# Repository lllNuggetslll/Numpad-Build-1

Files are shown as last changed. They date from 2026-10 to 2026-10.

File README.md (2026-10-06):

# Low-profile wireless numpad

A 21-key low-profile numpad: 4 columns × 6 rows, with three 2u keys ("0", "+", "Enter").

- **Controller:** nice!nano v2, running ZMK over Bluetooth.
- **Switches:** Gateron KS-33 low-profile switches in hotswap sockets.
- **Battery:** a 301230 LiPo with a low-battery LED.
- **Case:** a tilted 3D-printed case with a separate switch plate.

It's based on ceoloide's "not about money" ergogen design. The PCB is generated with
[ergogen](https://ergogen.xyz), routed with freerouting, and checked in KiCad 8. The case is generated
from the board itself, so the two always match.

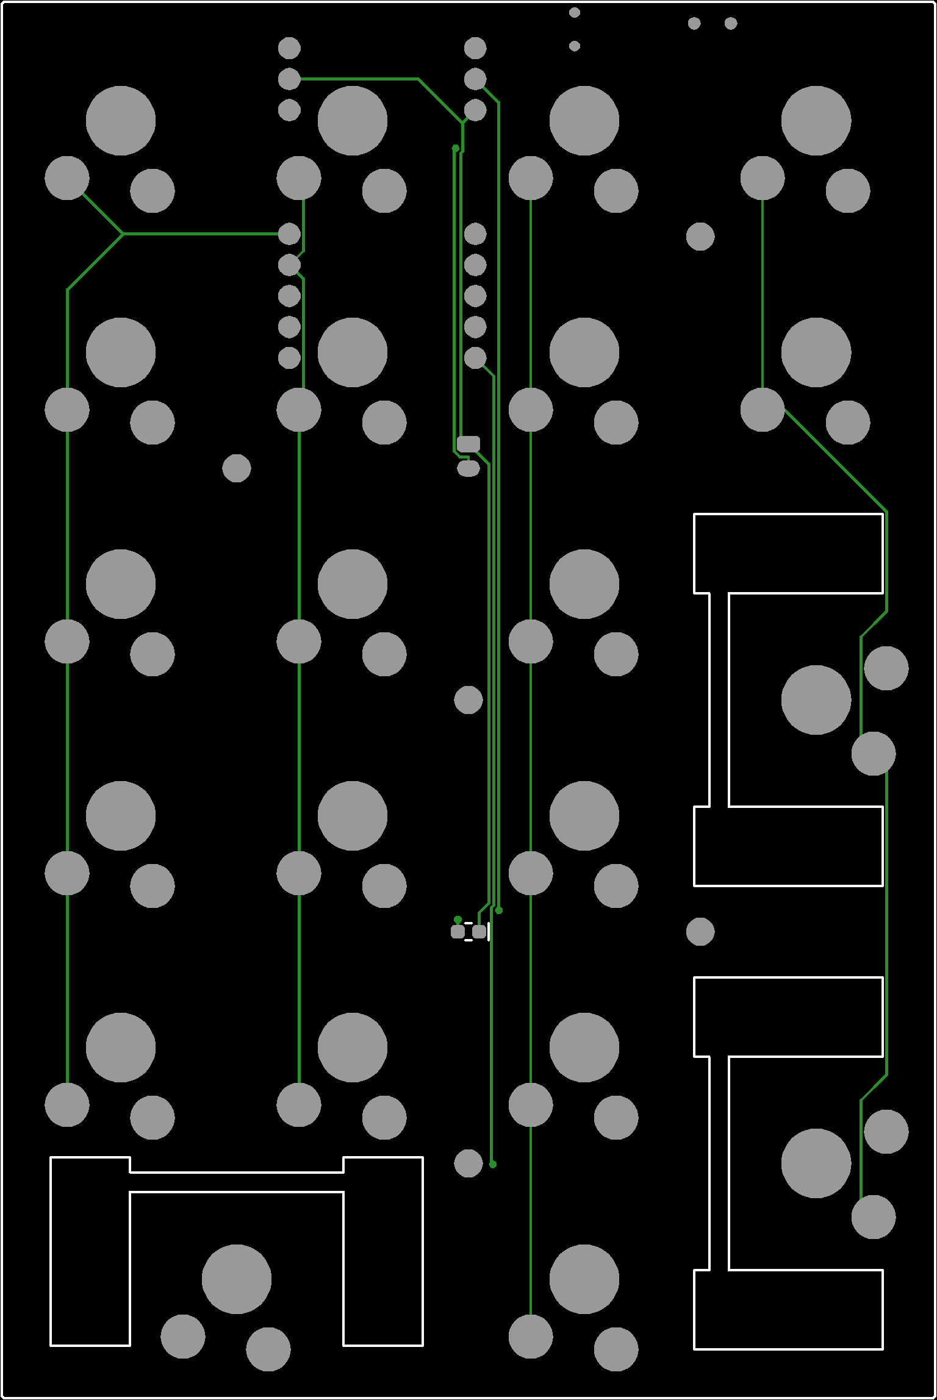
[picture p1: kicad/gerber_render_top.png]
PCB top


## Status

| Piece | State |
|---|---|
| PCB | Routed and DRC-clean. Gerbers are ready in `kicad/fab/numpad-gerbers.zip` (a PCBWay-ready package is `kicad/numpad.kicad_pcb.zip`). |
| Case and plate | `case/case_bottom.stl`, `case/case_plate.stl` |
| Firmware | Not written yet. ZMK needs a board definition using the pin map below. |

Before printing the whole plate, **test-print one stabilizer cutout**. Its notch depth and neck size come from a
drawing that isn't to scale.

## Shopping list

See **[SHOPPING_LIST.md](SHOPPING_LIST.md)**.

## Repository layout

| Path | What it is |
|---|---|
| `config.yaml` | Ergogen source of truth for the PCB: layout, footprints, outline. |
| `footprints/ceoloide/` | Upstream ceoloide footprints. |
| `footprints/custom/` | Local footprints. `mcu_nice_nano_sparse.js` adds an `omit_pins` option; `smd_0603.js` is for the LED and resistor. |
| `output/` | **Current board.** `pcbs/not_about_money.kicad_pcb` is routed (DRC report `pcbs/drc.rpt`, preview `routed.svg`); `not_about_money.unrouted.kicad_pcb` is the raw ergogen output. |
| `kicad/` | KiCad project for the current board (with the project's 0.2 mm edge-clearance rule), `fab/` (gerbers + drill + zip), and the PCBWay package `numpad.kicad_pcb.zip`. |
| `case/build_case.py` | Generates the case from the board: `case_bottom.jscad`, `case_plate.jscad`, `assembly.json`. |
| `case/viewer.html` | 3D viewer of the case, plate, PCB, parts, keycaps and battery. |
| `case/battery_fit.py` | Finds where LiPo cells fit under the tilted PCB. |
| Git history | Earlier design iterations (commit `c19e498` has every old `output_*` folder and config backup). |
| `CLAUDE.md` | Detailed design notes: coordinates, measurements, decisions, gotchas. |

## 1. Order the PCB

Upload `kicad/fab/numpad-gerbers.zip` to any PCB fab. For PCBWay, `kicad/numpad.kicad_pcb.zip` already includes their BOM, netlist and positions files. Order a 2-layer, 1.6 mm, standard-spec board. The
design values (0.25 mm tracks, 0.2 mm clearance, 0.6/0.3 mm vias) are within every fab's limits. The three
stabilizer cutouts are part of the board outline.

## 2. Print the case

- **`case/case_bottom.stl`:** print as-is (floor down). It has a 0.5 mm battery pocket in the floor and three
  windows in the back wall: USB-C, reset, and the power-switch lever. The USB-C port sits at the back of a
  12.5 × 6.5 mm recess so a cable head can reach it; the recess's back wall is flush with the port.
- **`case/case_plate.stl`:** print **upside down** (plate top on the bed). The edge rim and the spacer posts
  around the screws are on its underside.
- **Settings:** PLA or PETG, 0.2 mm layers. No supports needed.

## 3. Assemble

The switches go on the front of the PCB. **Everything else** goes on the back (side B), except the
low-battery LED, which is on the front.

1. **Trim three sockets.** On the hotswap sockets for the three 2u keys ("0", "+", "Enter"), sand
   **1.1 mm off the tip of the solder tab that points at the stabilizer cutout**, leaving about 1.4–1.5 mm of
   tab. Without this, that tab hits the stabilizer housing. Dry-fit each socket to find the right tab, then
   clean and tin it.
2. **Back side SMD parts:** solder the 21 diodes (mind the cathode band), the 21 hotswap sockets, the reset
   button, the power switch, and the 1 kΩ resistor.
3. **Front side:** solder the 0603 LED. It sits under a hole in the plate between the keycaps.
4. **Battery connector:** solder the JST PH on the back, then **trim its pins flush** on the front. They're
   3.4 mm long and the plate only leaves 1.6 mm above the PCB.
5. **nice!nano:** the controller mounts on the back, components facing **away** from the PCB, on standard
   male header pins with 2.5 mm plastic spacers.
   - Fit pins **only** where the PCB has holes: 16 pins (RAW, RST, GND ×2, P0, P1, P4–P8, P14–P16, P18,
     P19). The other 8 positions sit over switch pads and are left off on purpose.
   - Trim the pins on the front to about 1.4 mm.
6. **Battery:**
   - **Check polarity first.** On the JST footprint, the oval pad (pad 2) is **battery +** and the
     squarer pad (pad 1) is **battery −**. Many cheap LiPos have their plug wired the other way round.
     Measure with a multimeter before plugging in.
   - Stick the 301230 into the floor pocket with thin double-sided tape. Its lead runs from the notch at the
     pocket's end to the JST.
7. **Plate, stabilizers and switches:**
   - Clip the stabilizers into the plate. The wire bar faces the middle of the board.
   - Press the switches into the plate.
   - Lower the plate onto the PCB so the switch pins enter the sockets.
8. **Into the case:** angle the PCB in at the back first and slide it back, so the power lever slips
   through its window (it pokes about 0.5 mm out of the back) and the USB-C port slides into its window
   (it sits inside the wall, so it can't drop in from above). Then drop
   the front onto the pillars.
9. **Screws:** fit the countersunk M2 screws through the plate. Use **M2×8** at the back-left, back-right and
   centre pillars, and **M2×6** at the two front pillars. Tighten gently; they cut their own thread in the
   plastic.
10. **Keycaps.**

## 4. Firmware (ZMK)

The matrix is 4 columns × 6 rows, with diodes oriented column → row. The pin map below differs from the
original design, so the ZMK board/shield definition must match:

| Signal | nice!nano pin |
|---|---|
| Columns C1–C4 | P19, P18, P15, P14 |
| Row R1 | P16 |
| Rows R2–R6 | P4, P5, P6, P7, P8 |
| Low-battery LED (active high) | P0 (nRF P0.08) |
| Free spare | P1 |

VCC (3.3 V out) isn't connected. ZMK has no built-in low-battery LED, so blinking P0 when the battery is low
needs a small custom module. Keep it to a blink, because a steady LED drains the battery.

## Rebuilding from source

Requires ergogen v4.1.0 (`npm i -g ergogen@4.1.0`), KiCad 8 (its bundled Python provides `pcbnew`), and Java
15+ for freerouting 1.4.5.1.

1. **Generate the PCB.** Custom footprints only load when ergogen gets a *directory*. Copy `config.yaml` and
   `footprints/` into a scratch folder, then run:
   ```bash
   ergogen <scratch-folder> -o <scratch-folder>/out --clean
   ```
   Then copy `out/pcbs`, `out/outlines` and `out/cases` over the ones in `output/`. Don't point ergogen
   at `output/` directly: `--clean` empties the whole folder, including the routed board.
2. **Route it.** Export a Specctra DSN with `pcbnew.ExportSpecctraDSN`, then route:
   ```bash
   java -jar freerouting-1.4.5.1.jar -de board.dsn -do board.ses -mp 30
   ```
   Import the result with `pcbnew.ImportSpecctraSES`. Set copper-to-edge clearance to 0.2 mm (the side
   switches sit at the board edge), then run DRC:
   ```bash
   kicad-cli pcb drc --severity-error board.kicad_pcb
   ```
3. **Gerbers:**
   ```bash
   kicad-cli pcb export gerbers --output fab/ board.kicad_pcb
   ```
   ```bash
   kicad-cli pcb export drill --output fab/ board.kicad_pcb
   ```
   Then zip the `fab/` folder.
4. **Case.** Point `BOARD` at the top of `case/build_case.py` to the board, then run it with KiCad's Python. It
   prints the stack-up, a collision report, the battery spot and the screw lengths.
   ```bash
   "C:/Program Files/KiCad/8.0/bin/python.exe" case/build_case.py
   ```
   Render the jscad files to STL with the **v1** JSCAD CLI (v2 can't run them):
   ```bash
   npm install --prefix .jscad @jscad/cli@1
   ```
   ```bash
   .jscad/node_modules/.bin/openjscad case/case_bottom.jscad -o case/case_bottom.stl
   ```
   ```bash
   .jscad/node_modules/.bin/openjscad case/case_plate.jscad -o case/case_plate.stl
   ```
5. **View it.** Serve the case folder and open `http://localhost:8765/viewer.html`:
   ```bash
   python -m http.server 8765 --directory case
   ```

`CLAUDE.md` has the full design notes: the tilt and stack-up, where each part dimension came from (datasheet
vs estimate), the stabilizer geometry, and the controller pin constraints.

## Credits and licenses

- The base design and most footprints are by [ceoloide](https://github.com/ceoloide), with contributions by
  @infused-kim and @nxtk; see `footprints/ceoloide/LICENSE`.
- Some footprints are **CC BY-NC-SA 4.0**: the nice!nano and power-switch footprints, and therefore
  `footprints/custom/mcu_nice_nano_sparse.js`, which is derived from one of them. Others are MIT. Check the
  header of each file.
- The non-commercial clause means boards built from this repo shouldn't be sold.

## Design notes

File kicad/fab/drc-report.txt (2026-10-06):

** Drc report for numpad.kicad_pcb **
** Created on 2026-10-04T18:26:51-0700 **

** Found 83 DRC violations **
[silk_edge_clearance]: Silkscreen clipped by board edge
    Rule: board setup constraints silk; warning
    @(147.0000 mm, 61.2500 mm): Segment on Edge.Cuts
    @(147.5000 mm, 67.0000 mm): PCB Text 'JLCJLCJLCJLC' on B.Silkscreen
[lib_footprint_issues]: Footprint 'mounting_hole_npth' not found in library 'ceoloide'.
    Local override; warning
    @(128.5000 mm, 52.5000 mm): Footprint MH5
[lib_footprint_issues]: Footprint 'mounting_hole_npth' not found in library 'ceoloide'.
    Local override; warning
    @(147.5000 mm, 71.5000 mm): Footprint MH3
[lib_footprint_issues]: Footprint 'mounting_hole_npth' not found in library 'ceoloide'.
    Local override; warning
    @(128.5000 mm, 90.5000 mm): Footprint MH4
[lib_footprint_issues]: Footprint 'mounting_hole_npth' not found in library 'ceoloide'.
    Local override; warning
    @(147.5000 mm, 14.5000 mm): Footprint MH2
[lib_footprint_issues]: The current configuration does not include the library 'custom'.
    Local override; warning
    @(128.5000 mm, 71.5000 mm): Footprint LED1
[lib_footprint_issues]: Footprint 'mounting_hole_npth' not found in library 'ceoloide'.
    Local override; warning
    @(109.5000 mm, 33.5000 mm): Footprint MH1
[lib_footprint_issues]: Footprint 'switch_gateron_ks27_ks33' not found in library 'ceoloide'.
    Local override; warning
    @(157.0000 mm, 90.5000 mm): Footprint S20
[lib_footprint_issues]: Footprint 'switch_gateron_ks27_ks33' not found in library 'ceoloide'.
    Local override; warning
    @(119.0000 mm, 5.0000 mm): Footprint S10
[lib_footprint_issues]: Footprint 'mcu_nice_nano' not found in library 'ceoloide'.
    Local override; warning
    @(121.4400 mm, 11.7500 mm): Footprint MCU1
[lib_footprint_issues]: Footprint 'diode_tht_sod123' not found in library 'ceoloide'.
    Local override; warning
    @(107.1000 mm, 3.7500 mm): Footprint D6
[lib_footprint_issues]: Footprint 'switch_gateron_ks27_ks33' not found in library 'ceoloide'.
    Local override; warning
    @(119.0000 mm, 24.0000 mm): Footprint S9
[lib_footprint_issues]: Footprint 'diode_tht_sod123' not found in library 'ceoloide'.
    Local override; warning
    @(126.1000 mm, 60.7500 mm): Footprint D8
[lib_footprint_issues]: Footprint 'diode_tht_sod123' not found in library 'ceoloide'.
    Local override; warning
    @(107.1000 mm, 22.7500 mm): Footprint D5
[lib_footprint_issues]: Footprint 'switch_gateron_ks27_ks33' not found in library 'ceoloide'.
    Local override; warning
    @(119.0000 mm, 62.0000 mm): Footprint S7
[lib_footprint_issues]: Footprint 'switch_gateron_ks27_ks33' not found in library 'ceoloide'.
    Local override; warning
    @(100.0000 mm, 5.0000 mm): Footprint S5
[lib_footprint_issues]: Footprint 'diode_tht_sod123' not found in library 'ceoloide'.
    Local override; warning
    @(116.6000 mm, 98.7500 mm): Footprint D1
[lib_footprint_issues]: Footprint 'switch_gateron_ks27_ks33' not found in library 'ceoloide'.
    Local override; warning
    @(157.0000 mm, 5.0000 mm): Footprint S18
[lib_footprint_issues]: Footprint 'diode_tht_sod123' not found in library 'ceoloide'.
    Local override; warning
    @(164.1000 mm, 89.2500 mm): Footprint D18
[lib_footprint_issues]: Footprint 'switch_gateron_ks27_ks33' not found in library 'ceoloide'.
    Local override; warning
    @(100.0000 mm, 62.0000 mm): Footprint S2
[lib_footprint_issues]: Footprint 'diode_tht_sod123' not found in library 'ceoloide'.
    Local override; warning
    @(145.1000 mm, 79.7500 mm): Footprint D13
[lib_footprint_issues]: Footprint 'diode_tht_sod123' not found in library 'ceoloide'.
    Local override; warning
    @(145.1000 mm, 98.7500 mm): Footprint D12
[lib_footprint_issues]: Footprint 'diode_tht_sod123' not found in library 'ceoloide'.
    Local override; warning
    @(126.1000 mm, 22.7500 mm): Footprint D10
[lib_footprint_issues]: Footprint 'diode_tht_sod123' not found in library 'ceoloide'.
    Local override; warning
    @(107.1000 mm, 41.7500 mm): Footprint D4
[lib_footprint_issues]: Footprint 'diode_tht_sod123' not found in library 'ceoloide'.
    Local override; warning
    @(126.1000 mm, 3.7500 mm): Footprint D11
[lib_footprint_issues]: Footprint 'switch_gateron_ks27_ks33' not found in library 'ceoloide'.
    Local override; warning
    @(138.0000 mm, 62.0000 mm): Footprint S13
[lib_footprint_issues]: Footprint 'switch_gateron_ks27_ks33' not found in library 'ceoloide'.
    Local override; warning
    @(138.0000 mm, 5.0000 mm): Footprint S16
[lib_footprint_issues]: Footprint 'switch_gateron_ks27_ks33' not found in library 'ceoloide'.
    Local override; warning
    @(138.0000 mm, 100.0000 mm): Footprint S11
[lib_footprint_issues]: Footprint 'diode_tht_sod123' not found in library 'ceoloide'.
    Local override; warning
    @(107.1000 mm, 79.7500 mm): Footprint D2
[lib_footprint_issues]: Footprint 'diode_tht_sod123' not found in library 'ceoloide'.
    Local override; warning
    @(126.1000 mm, 41.7500 mm): Footprint D9
[lib_footprint_issues]: Footprint 'switch_gateron_ks27_ks33' not found in library 'ceoloide'.
    Local override; warning
    @(157.0000 mm, 24.0000 mm): Footprint S17
[lib_footprint_issues]: Footprint 'switch_gateron_ks27_ks33' not found in library 'ceoloide'.
    Local override; warning
    @(119.0000 mm, 81.0000 mm): Footprint S6
[lib_footprint_issues]: Footprint 'battery_connector_jst_ph_2' not found in library 'ceoloide'.
    Local override; warning
    @(128.5000 mm, 32.5000 mm): Footprint JST1
[lib_footprint_issues]: Footprint 'switch_gateron_ks27_ks33' not found in library 'ceoloide'.
    Local override; warning
    @(109.5000 mm, 100.0000 mm): Footprint S19
[lib_footprint_issues]: The current configuration does not include the library 'custom'.
    Local override; warning
    @(128.5000 mm, 71.5000 mm): Footprint R1
[lib_footprint_issues]: Footprint 'switch_gateron_ks27_ks33' not found in library 'ceoloide'.
    Local override; warning
    @(119.0000 mm, 43.0000 mm): Footprint S8
[lib_footprint_issues]: Footprint 'switch_gateron_ks27_ks33' not found in library 'ceoloide'.
    Local override; warning
    @(100.0000 mm, 43.0000 mm): Footprint S3
[lib_footprint_issues]: Footprint 'diode_tht_sod123' not found in library 'ceoloide'.
    Local override; warning
    @(164.1000 mm, 51.2500 mm): Footprint D19
[lib_footprint_issues]: Footprint 'diode_tht_sod123' not found in library 'ceoloide'.
    Local override; warning
    @(145.1000 mm, 22.7500 mm): Footprint D16
[lib_footprint_issues]: Footprint 'switch_gateron_ks27_ks33' not found in library 'ceoloide'.
    Local override; warning
    @(100.0000 mm, 81.0000 mm): Footprint S1
[lib_footprint_issues]: Footprint 'diode_tht_sod123' not found in library 'ceoloide'.
    Local override; warning
    @(145.1000 mm, 3.7500 mm): Footprint D17
[lib_footprint_issues]: Footprint 'diode_tht_sod123' not found in library 'ceoloide'.
    Local override; warning
    @(145.1000 mm, 60.7500 mm): Footprint D14
[lib_footprint_issues]: Footprint 'diode_tht_sod123' not found in library 'ceoloide'.
    Local override; warning
    @(126.1000 mm, 79.7500 mm): Footprint D7
[lib_footprint_issues]: Footprint 'diode_tht_sod123' not found in library 'ceoloide'.
    Local override; warning
    @(145.1000 mm, 41.7500 mm): Footprint D15
[lib_footprint_issues]: Footprint 'switch_gateron_ks27_ks33' not found in library 'ceoloide'.
    Local override; warning
    @(138.0000 mm, 43.0000 mm): Footprint S14
[lib_footprint_issues]: Footprint 'switch_gateron_ks27_ks33' not found in library 'ceoloide'.
    Local override; warning
    @(157.0000 mm, 52.5000 mm): Footprint S21
[lib_footprint_issues]: Footprint 'diode_tht_sod123' not found in library 'ceoloide'.
    Local override; warning
    @(164.1000 mm, 3.7500 mm): Footprint D21
[lib_footprint_issues]: Footprint 'power_switch_smd_side' not found in library 'ceoloide'.
    Local override; warning
    @(148.5000 mm, -2.9550 mm): Footprint PWR1
[lib_footprint_issues]: Footprint 'diode_tht_sod123' not found in library 'ceoloide'.
    Local override; warning
    @(164.1000 mm, 22.7500 mm): Footprint D20
[lib_footprint_issues]: Footprint 'diode_tht_sod123' not found in library 'ceoloide'.
    Local override; warning
    @(107.1000 mm, 60.7500 mm): Footprint D3
[lib_footprint_issues]: Footprint 'switch_gateron_ks27_ks33' not found in library 'ceoloide'.
    Local override; warning
    @(100.0000 mm, 24.0000 mm): Footprint S4
[lib_footprint_issues]: Footprint 'switch_gateron_ks27_ks33' not found in library 'ceoloide'.
    Local override; warning
    @(138.0000 mm, 81.0000 mm): Footprint S12
[lib_footprint_issues]: Footprint 'reset_switch_smd_side' not found in library 'ceoloide'.
    Local override; warning
    @(137.2000 mm, -2.5000 mm): Footprint RST1
[lib_footprint_issues]: Footprint 'switch_gateron_ks27_ks33' not found in library 'ceoloide'.
    Local override; warning
    @(138.0000 mm, 24.0000 mm): Footprint S15
[silk_over_copper]: Silkscreen clipped by solder mask
    Local override; warning
    @(147.5000 mm, 29.5000 mm): PCB Text ''Not about money' v0.1 by ceoloide' on B.Silkscreen
[silk_over_copper]: Silkscreen clipped by solder mask
    Local override; warning
    @(147.5000 mm, 67.0000 mm): PCB Text 'JLCJLCJLCJLC' on B.Silkscreen
[silk_over_copper]: Silkscreen clipped by solder mask
    Local override; warning
    @(115.1500 mm, -2.2800 mm): Segment on B.Silkscreen
[silk_over_copper]: Silkscreen clipped by solder mask
    Local override; warning
    @(115.1500 mm, 28.3200 mm): Segment on B.Silkscreen
[silk_over_copper]: Silkscreen clipped by solder mask
    Local override; warning
    @(130.3900 mm, -2.2800 mm): Segment on B.Silkscreen
[silk_over_copper]: Silkscreen clipped by solder mask
    Local override; warning
    @(130.3900 mm, 28.3200 mm): Segment on B.Silkscreen
[silk_over_copper]: Silkscreen clipped by solder mask
    Local override; warning
    @(125.9100 mm, 21.9100 mm): Footprint Text 'R5' of MCU1
[silk_over_copper]: Silkscreen clipped by solder mask
    Local override; warning
    @(116.9700 mm, 6.6700 mm): Footprint Text 'V+' of MCU1
[silk_over_copper]: Silkscreen clipped by solder mask
    Local override; warning
    @(116.9700 mm, 21.9100 mm): Footprint Text 'C4' of MCU1
[silk_over_copper]: Silkscreen clipped by solder mask
    Local override; warning
    @(125.9100 mm, 24.4500 mm): Footprint Text 'R6' of MCU1
[silk_over_copper]: Silkscreen clipped by solder mask
    Local override; warning
    @(116.9700 mm, 24.4500 mm): Footprint Text 'R1' of MCU1
[silk_over_copper]: Silkscreen clipped by solder mask
    Local override; warning
    @(116.9700 mm, 4.1300 mm): Footprint Text 'RS' of MCU1
[silk_over_copper]: Silkscreen clipped by solder mask
    Local override; warning
    @(163.7000 mm, 89.0000 mm): Segment on B.Silkscreen
[silk_over_copper]: Silkscreen clipped by solder mask
    Local override; warning
    @(164.1000 mm, 89.0000 mm): Segment on B.Silkscreen
[silk_over_copper]: Silkscreen clipped by solder mask
    Local override; warning
    @(164.1000 mm, 89.6000 mm): Segment on B.Silkscreen
[silk_over_copper]: Silkscreen clipped by solder mask
    Local override; warning
    @(134.8600 mm, 29.4400 mm): Segment on B.Silkscreen
[silk_over_copper]: Silkscreen clipped by solder mask
    Local override; warning
    @(134.8600 mm, 30.3600 mm): Segment on B.Silkscreen
[silk_over_copper]: Silkscreen clipped by solder mask
    Local override; warning
    @(163.7000 mm, 51.0000 mm): Segment on B.Silkscreen
[silk_over_copper]: Silkscreen clipped by solder mask
    Local override; warning
    @(164.1000 mm, 51.0000 mm): Segment on B.Silkscreen
[silk_over_copper]: Silkscreen clipped by solder mask
    Local override; warning
    @(164.1000 mm, 51.6000 mm): Segment on B.Silkscreen
[silk_overlap]: Silkscreen overlap
    Rule: board setup constraints silk; warning
    @(147.5000 mm, 29.5000 mm): PCB Text ''Not about money' v0.1 by ceoloide' on B.Silkscreen
    @(134.8600 mm, 29.4400 mm): Segment on B.Silkscreen
[silk_overlap]: Silkscreen overlap
    Rule: board setup constraints silk; warning
    @(147.5000 mm, 29.5000 mm): PCB Text ''Not about money' v0.1 by ceoloide' on B.Silkscreen
    @(134.8600 mm, 30.3600 mm): Segment on B.Silkscreen
[silk_overlap]: Silkscreen overlap
    Rule: board setup constraints silk; warning
    @(125.9100 mm, 21.9100 mm): Footprint Text 'R5' of MCU1
    @(126.1000 mm, 22.5000 mm): Segment on B.Silkscreen
[silk_overlap]: Silkscreen overlap
    Rule: board setup constraints silk; warning
    @(125.9100 mm, 4.1300 mm): Footprint Text 'GN' of MCU1
    @(125.7000 mm, 3.5000 mm): Segment on B.Silkscreen
[silk_overlap]: Silkscreen overlap
    Rule: board setup constraints silk; warning
    @(125.9100 mm, 4.1300 mm): Footprint Text 'GN' of MCU1
    @(126.1000 mm, 4.1000 mm): Segment on B.Silkscreen
[silk_overlap]: Silkscreen overlap
    Rule: board setup constraints silk; warning
    @(125.9100 mm, 4.1300 mm): Footprint Text 'GN' of MCU1
    @(126.1000 mm, 4.1000 mm): Segment on B.Silkscreen
[silk_overlap]: Silkscreen overlap
    Rule: board setup constraints silk; warning
    @(125.9100 mm, 4.1300 mm): Footprint Text 'GN' of MCU1
    @(126.1000 mm, 4.5000 mm): Segment on B.Silkscreen
[silk_overlap]: Silkscreen overlap
    Rule: board setup constraints silk; warning
    @(125.9100 mm, 4.1300 mm): Footprint Text 'GN' of MCU1
    @(126.1000 mm, 4.1000 mm): Segment on B.Silkscreen
[silk_overlap]: Silkscreen overlap
    Rule: board setup constraints silk; warning
    @(125.9100 mm, 4.1300 mm): Footprint Text 'GN' of MCU1
    @(126.5000 mm, 3.5000 mm): Segment on B.Silkscreen

** Found 0 unconnected pads **

** Found 0 Footprint errors **

** End of Report **

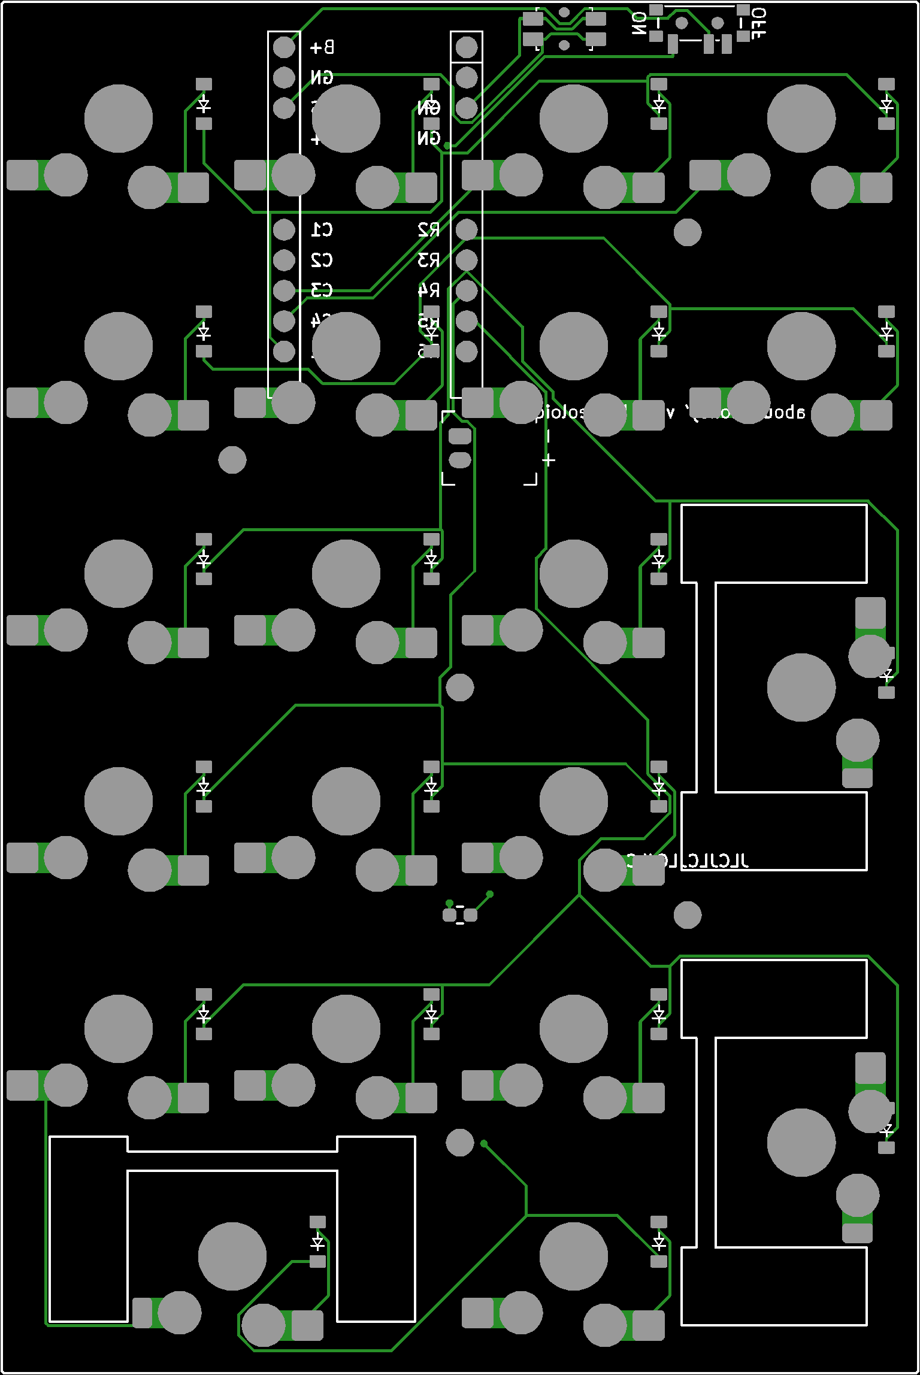
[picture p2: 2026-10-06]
kicad/gerber_render_bottom.png

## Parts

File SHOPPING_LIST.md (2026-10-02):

# Shopping list

Everything needed to build one numpad: 21 keys, wireless, Gateron low-profile hotswap.
Quantities are per keyboard. Buy a few spares of the small parts.

## Electronics

| Qty | Part | Exact part / spec | Notes |
|---|---|---|---|
| 1 | PCB | 2-layer, 1.6 mm FR-4, from `kicad/fab/numpad-gerbers.zip` | Any fab (JLCPCB, PCBWay, …). The 3 stabilizer cutouts are in the board outline, so no extra milling is needed. |
| 1 | Controller | **nice!nano v2** | Wireless nRF52840 (ZMK). |
| 16 | Header pins | 2.54 mm single-row male headers with standard **2.5 mm** plastic | Only 16 of the 24 positions are used (see the README). Buy a 1×40 strip. |
| 21 | Hotswap sockets | **Gateron Low Profile Hot-swap 2.0, KS-2P02B01-02** | Must be the **low-profile** version (-02). The regular -01 socket doesn't fit. Sold in packs of 70/110. |
| 21 | Diodes | 1N4148W, **SOD-123** | |
| 1 | Reset button | **Panasonic EVQ-PUA02K** (or EVQ-PUC02K / EVQ-PUL02K) | Side-push SMD, 4.7 × 3.5 mm. PUA02K is the easy-to-find one; it has no locating pegs, so the two small holes stay empty. Not EVQ-PUD02K (3.2 mm deep). |
| 1 | Power switch | **MSK-12C02-style side slide switch, H = 2.5 mm** (7-pin SMD, 6.65 × 2.7 × 1.4 body, 1.5 mm pin pitch) | Must be the **2.5 mm lever** version, so it sticks ~0.5 mm out of the case. The 1.5/2.0 versions (and the Alps SSSS811101) fit the pads but end inside the wall. |
| 1 | Battery connector | **JST PH S2B-PH-K-S** | 2-pin, 2.0 mm, side entry, through-hole. |
| 1 | Low-battery LED | **Lite-On LTST-C191KRKT** (0603, red, 0.55 mm tall) | Any 0603 LED up to ~1.4 mm tall fits. |
| 1 | LED resistor | 1 kΩ, 0603 | |
| 1 | Battery | **301230 LiPo**, 3.7 V, ~110 mAh, 3 × 12 × 30 mm, with protection circuit and a **JST PH 2.0** plug | The case has a pocket sized for this cell. **Check the plug polarity** before connecting it (see the README). |

## Switches and keycaps

| Qty | Part | Exact part / spec | Notes |
|---|---|---|---|
| 21 | Switches | **Gateron KS-33 Low Profile 2.0** (e.g. Brown, KS-33E10B055NN-Y24) | Any KS-33 variant. Sold in packs of 35/70/110. |
| 3 | Stabilizers | **Gateron Low Profile Plate-Mounted Stabilizer 2U, KS-57B210T** | For the "0", "+" and "Enter" keys. |
| 18 | Keycaps, 1u | Low-profile keycaps for Gateron LP / KS-33 switches, **18 mm** | Standard-height MX keycaps are too tall for this build. |
| 1 | Keycap, 2u horizontal | Same profile, 2u wide (37 × 18 mm) | "0" key. |
| 2 | Keycaps, 2u vertical | Same profile, 2u tall (18 × 37 mm) | "+" and "Enter". |

## Case and hardware

| Qty | Part | Exact part / spec | Notes |
|---|---|---|---|
| 1 | Case bottom (3D print) | `case/case_bottom.stl` | PLA or PETG, 0.2 mm layers, no supports needed. |
| 1 | Switch plate (3D print) | `case/case_plate.stl` | Print it **upside down** (top face on the bed), because the rim and spacer posts are on its underside. |
| 3 | Screws | **M2 × 8 countersunk** (DIN 965 / ISO 7046), self-tapping or thread-forming for plastic | For the pillars at the back-left, back-right and centre. |
| 2 | Screws | **M2 × 6 countersunk**, same type | For the two front pillars, which are shorter. |
| 1 | Double-sided tape | Thin foam or VHB strip, ~10 × 25 mm | Holds the battery in its pocket. |
| 4 | Rubber feet (optional) | Small adhesive bumpers, ≤ 8 mm | |

## Tools

- Soldering iron with a fine tip, solder, flux.
- Flush cutters, for trimming the header pins and the JST pins.
- Rotary tool or a fine file, to shorten one solder tab on 3 of the hotswap sockets (see the README).
- Tweezers, a multimeter, and a USB-C cable for flashing.
- 3D printer, or a printing service.

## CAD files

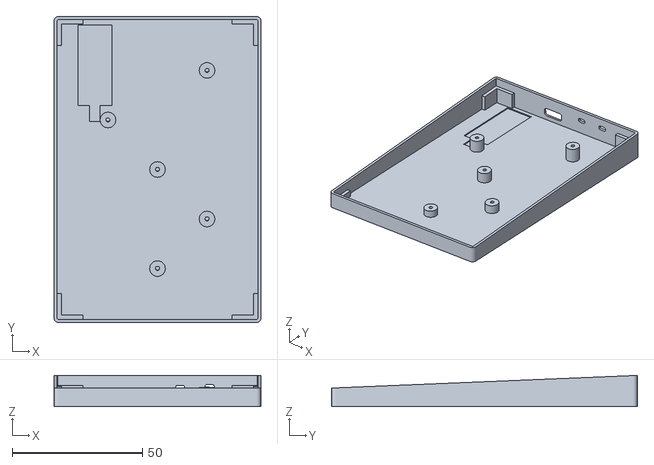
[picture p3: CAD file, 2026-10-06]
case/case_bottom.stl
79.4 x 117.4 x 12.0

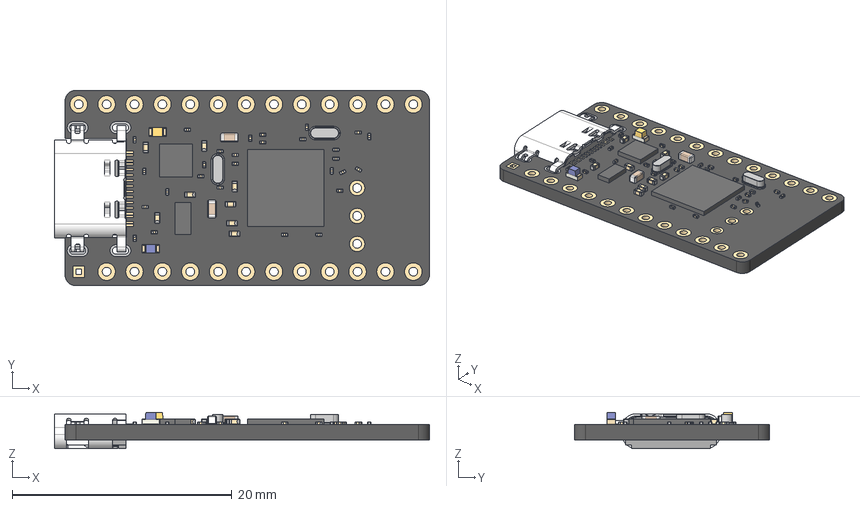
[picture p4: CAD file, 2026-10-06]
kicad/3d/nice_nano_v2.step
34.2 x 17.8 x 3.28 mm
nice!nano v1.0
SSOP16
LED_0603_1608Metric_ON
LED_0603_1608Metric_ON_1
Crystal Oscillator
Crystal Oscillator_1
usb4520-03-0-a_1
C0201 x 21
C0402 x 8
C0201_1 x 7

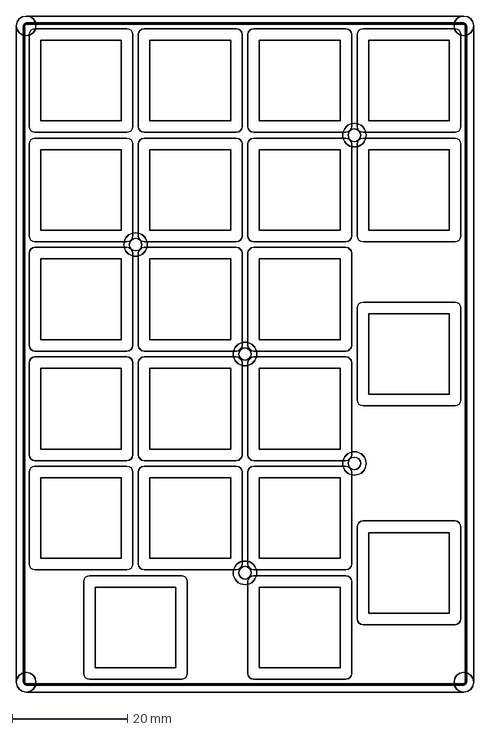
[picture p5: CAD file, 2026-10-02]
output/outlines/preview.dxf
79.4 x 117.4 mm

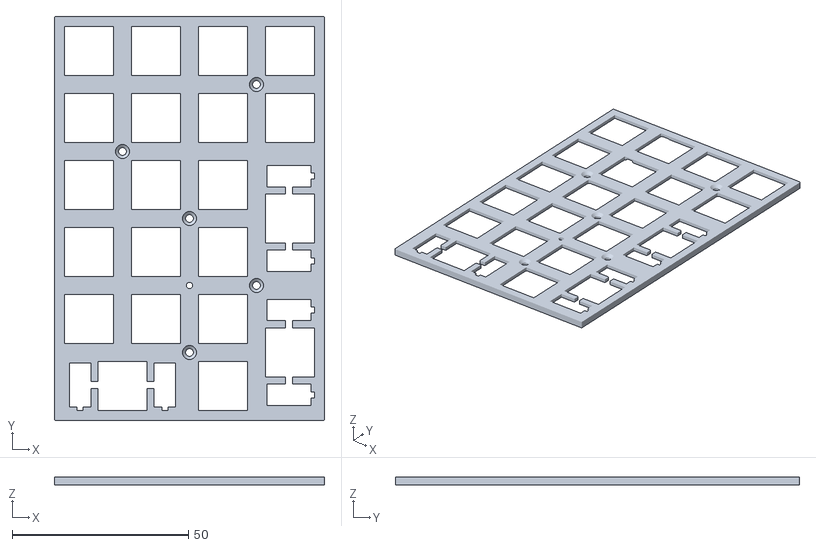
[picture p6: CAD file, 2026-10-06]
case/case_plate.stl
76.6 x 114.6 x 2.20

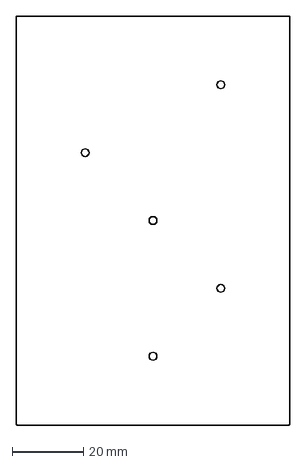
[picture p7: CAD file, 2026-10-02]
output/outlines/not_about_money_outline.dxf
76.5 x 114.5 mm

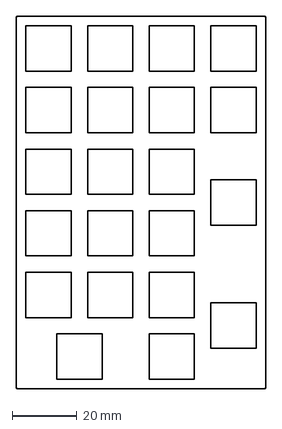
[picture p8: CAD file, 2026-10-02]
output/outlines/top_case_inner_plate.dxf
77.0 x 115.0 mm

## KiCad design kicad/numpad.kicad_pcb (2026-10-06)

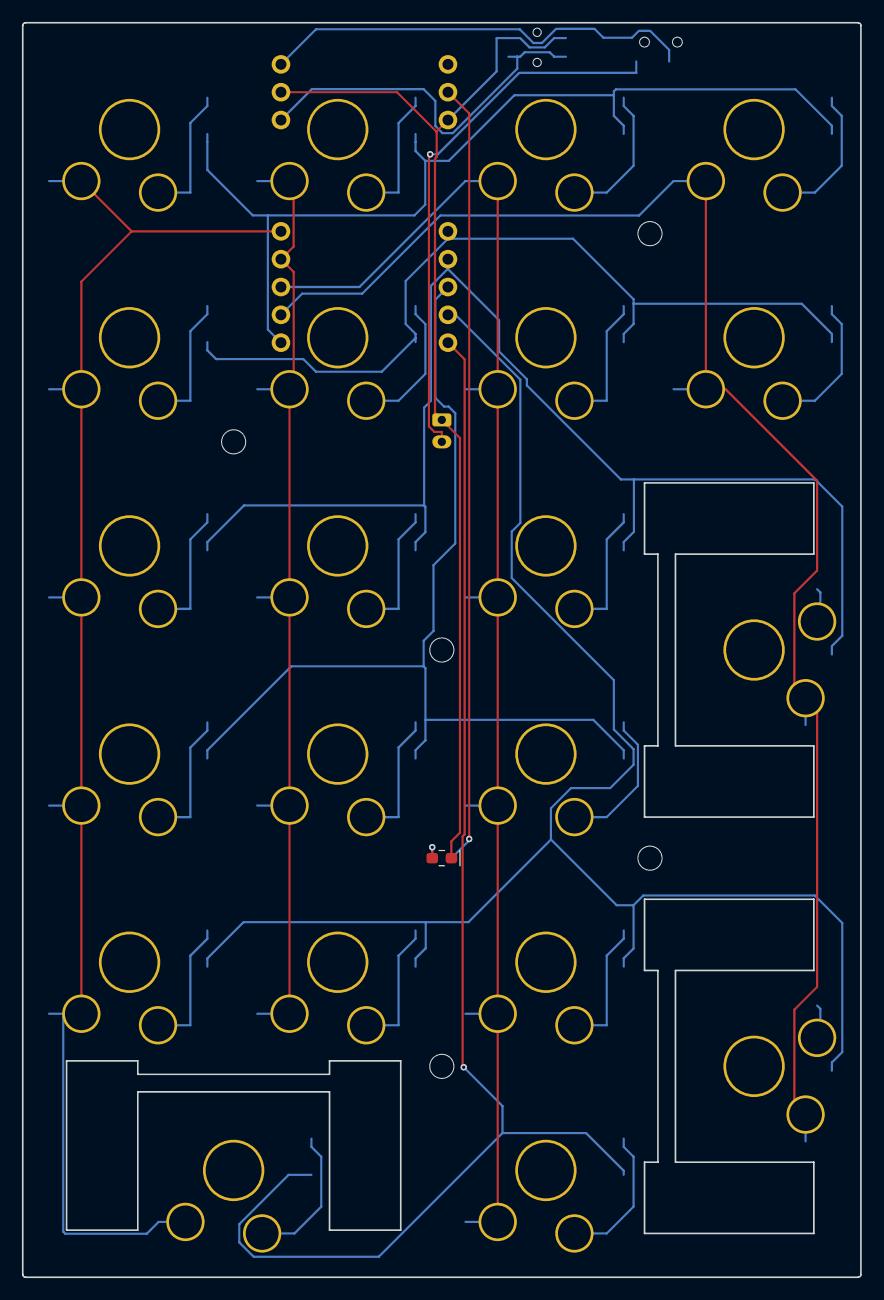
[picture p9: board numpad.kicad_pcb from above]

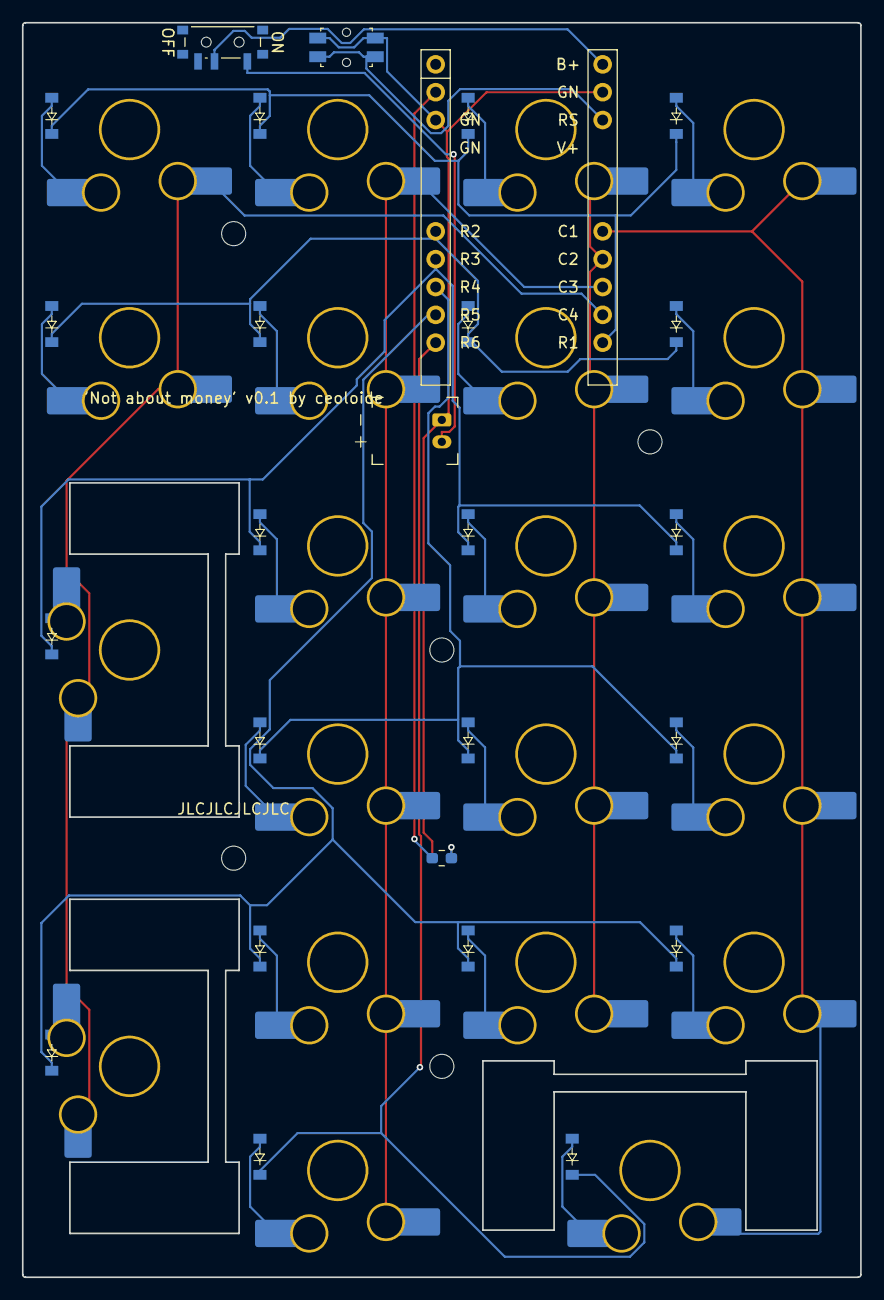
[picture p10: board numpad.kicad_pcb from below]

Board: 2 copper layers, 76.5 x 114.5 mm, 53 parts (47 on the bottom side), 37 nets.

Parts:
D1, D2, D3, D4, D5, D6, D7, D8, D9, D10, D11, D12, D13, D14, D15, D16, D17, D18, D19, D20, D21: diode_tht_sod123
JST1: battery_connector_jst_ph_2
LED1: smd_0603
MCU1: mcu_nice_nano
MH1, MH2, MH3, MH4, MH5: mounting_hole_npth
PWR1: power_switch_smd_side
R1: smd_0603
RST1: reset_switch_smd_side
S1, S2, S3, S4, S5, S6, S7, S8, S9, S10, S11, S12, S13, S14, S15, S16, S17, S18, S19, S20, S21: switch_gateron_ks27_ks33

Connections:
BAT_P: JST1.2, PWR1.1
C1: MCU1.18, S1.1, S2.1, S3.1, S4.1, S5.1, S19.1
C2: MCU1.17, S6.1, S7.1, S8.1, S9.1, S10.1
C3: MCU1.16, S11.1, S12.1, S13.1, S14.1, S15.1, S16.1
C4: MCU1.15, S17.1, S18.1, S20.1, S21.1
GND: JST1.1, LED1.2, MCU1.3, MCU1.23, RST1.1, RST1.3
LED_A: LED1.1, R1.2
P0: MCU1.2, R1.1
R1: D6.1, D11.1, D17.1, D21.1, MCU1.14
R2: D5.1, D10.1, D16.1, D20.1, MCU1.7
R3: D4.1, D9.1, D15.1, D19.1, MCU1.8
R4: D3.1, D8.1, D14.1, MCU1.9
R5: D2.1, D7.1, D13.1, D18.1, MCU1.10
R6: D1.1, D12.1, MCU1.11
RAW: MCU1.24, PWR1.2
RST: MCU1.22, RST1.2, RST1.4
c1_r1: D6.2, S5.2
c1_r2: D5.2, S4.2
c1_r3: D4.2, S3.2
c1_r4: D3.2, S2.2
c1_r5: D2.2, S1.2
c1_r6: D1.2, S19.2
c2_r1: D11.2, S10.2
c2_r2: D10.2, S9.2
c2_r3: D9.2, S8.2
c2_r4: D8.2, S7.2
c2_r5: D7.2, S6.2
c3_r1: D17.2, S16.2
c3_r2: D16.2, S15.2
c3_r3: D15.2, S14.2
c3_r4: D14.2, S13.2
c3_r5: D13.2, S12.2
c3_r6: D12.2, S11.2
c4_r1: D21.2, S18.2
c4_r2: D20.2, S17.2
c4_r3: D19.2, S21.2
c4_r5: D18.2, S20.2

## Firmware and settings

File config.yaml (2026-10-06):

units:
  extra_spread: 0
  extra_padding: 0
  board_expand: 0.25 # 18mm keycaps on 19mm pitch: 1mm gap to the case wall (0.25 PCB tolerance)

  # Physical measures
  screw_radius: 1.1 # M2 screws
  screw_diameter: screw_radius * 2
  screw_head_radius: 2.05
  screw_head_diameter: screw_head_radius * 2
  spacer_radius: 2.15 # M2 standoffs
  spacer_diameter: spacer_radius * 2
  fillet_radius: 0.5

  # Case variables
  case_wall_thickness: 1.2
  pcb_to_case_wall_tolerance: 0.25
  bottom_plate_thickness: 1.0
  top_plate_thickness: 1.6
  internal_distance_between_plates: 4
points:
  zones:
    # Main key matrix
    matrix:
      key:
        spread: u + extra_spread
        padding: u + extra_padding
        tags:
          - key
      anchor:
        shift: [100, -100] # Fix KiCad placement
      columns:
        c1:
          key.column_net: C1
          rows.r6:
            width: 2u
            adjust.shift: [0.5u, 0]
        c2:
          key.column_net: C2
          rows.r6.skip: true
        c3:
          key.column_net: C3
        c4:
          key.column_net: C4
          rows:
            r3:
              height: 2u
              adjust.shift: [0, -0.5u]
            r4.skip: true
            r5:
              height: 2u
              adjust.shift: [0, -0.5u]
            r6.skip: true
      rows:
        r6:
          row_net: R6
        r5:
          row_net: R5
        r4:
          row_net: R4
        r3:
          row_net: R3
        r2:
          row_net: R2
        r1:
          row_net: R1
    screw_pcb_left_top:
      key.tags:
        - helper
        - screw
      anchor:
        - ref: matrix_c1_r2
          shift: [(u + extra_spread) / 2, -(u + extra_padding) / 2]
    screw_pcb_right_top:
      key.tags:
        - helper
        - screw
      anchor:
        - ref: matrix_c4_r1
          shift: [-(u + extra_spread) / 2, -(u + extra_padding) / 2]
    screw_pcb_right_bottom:
      key.tags:
        - helper
        - screw
      anchor:
        - ref: matrix_c4_r6
          # one row further back than the key corner: the lower tall key's stabilizer bar runs
          # through the corner position
          shift: [-(u + extra_spread) / 2, (u + extra_padding) / 2 + u]
    screw_pcb_left_bottom:
      key.tags:
        - helper
        - screw
      anchor:
        - ref: matrix_c3_r6
          # key crossing just right of the "0" key: past the end of its stabilizer bar
          shift: [-(u + extra_spread) / 2, (u + extra_padding) / 2]
    screw_pcb_center:
      key.tags:
        - helper
        - screw
      anchor:
        - ref: matrix_c2_r3
          shift: [(u + extra_spread) / 2, -(u + extra_padding) / 2]
outlines:
  _keycaps:
    - what: rectangle
      where: [key]
      size: 18
      fillet: 1
  _switches:
    - what: rectangle
      where: [key]
      size: 14
  _screws:
    - what: circle
      where: /screw_pcb/
      radius: screw_radius
  _screw_heads:
    - what: circle
      where: /screw_pcb/
      radius: screw_head_radius
  _spacers:
    - what: circle
      where: /screw_pcb/
      radius: spacer_radius
  _matrix_outline:
    - what: polygon
      points:
        - ref: matrix_c1_r1
          shift: [-u/2, u/2]
        - ref: matrix_c4_r1
          shift: [u/2, u/2]
        - ref: matrix_c4_r5
          shift: [u/2, -u]
        - ref: matrix_c1_r6
          shift: [-u, -u/2]
  _board_outline:
    - what: outline
      name: _matrix_outline
      expand: board_expand

  _stab_holes:
    # Gateron LP plate-mount stabilizer (KS-57B210T, from its STEP model). Per 2u key: two housing
    # cutouts (6.5 x 15.45, offset 2.275 toward the bar) joined by a 1.6 slot for the bar, which hangs
    # 0.225mm into the PCB. Bars point inward (toward the board centre).
    - what: rectangle
      where: matrix_c1_r6
      size: [6.5, 15.45]
      adjust.shift: [12, 2.275]
    - what: rectangle
      where: matrix_c1_r6
      size: [6.5, 15.45]
      adjust.shift: [-12, 2.275]
    - what: rectangle
      where: matrix_c1_r6
      size: [24, 1.6]
      adjust.shift: [0, 7.975]
    - what: rectangle
      where: [matrix_c4_r3, matrix_c4_r5]
      size: [15.45, 6.5]
      adjust.shift: [-2.275, 12]
    - what: rectangle
      where: [matrix_c4_r3, matrix_c4_r5]
      size: [15.45, 6.5]
      adjust.shift: [-2.275, -12]
    - what: rectangle
      where: [matrix_c4_r3, matrix_c4_r5]
      size: [1.6, 24]
      adjust.shift: [-7.975, 0]
  _pcb_outline:
    - what: outline
      name: _board_outline
    - what: outline
      name: _stab_holes
      operation: subtract

  not_about_money_outline:
    - what: outline
      name: _board_outline
    - what: outline
      name: _screws
      operation: stack
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

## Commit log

2026-10-02 Initial commit: low-profile wireless numpad (PCB, case, BOM)
    21-key Gateron KS-33 low-profile hotswap numpad with a nice!nano (ZMK),
    generated with ergogen from ceoloide's "not about money" design.
    - config.yaml + footprints: ergogen source; output_stabfix is the current
    routed, DRC-clean board, with gerbers in output/numpad/fab
    - case/: board-driven tilted case + switch plate generator (jscad/STL),
    3D assembly viewer, battery fit search
    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
    [case_bottom.stl, case_plate.stl, gateron.kicad_pcb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]
2026-10-02 Clean up: keep only the current design
    - Remove the earlier design iterations (output_gateron, output_toplayout,
    output_keygap, output_led), the original choc output and the config /
    case-script backups; they remain in commit c19e498
    - Move the current routed board from output_stabfix/ to output/
    - Point case/build_case.py, README and CLAUDE.md at the new paths; warn
    against running ergogen with --clean on output/
    [case_bottom.stl, case_plate.stl, gateron.kicad_pcb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]
2026-10-02 Move KiCad project to kicad/ and prune leftovers
    - output/numpad/ -> kicad/: project, current gerbers (fab/), renders, DRC
    report and the PCBWay order package (numpad.kicad_pcb.zip), so a future
    ergogen run into output/ can't touch it
    - Drop choc-era and pre-stabfix backups, stale gerbers and the old nested
    project folder (still available in earlier commits)
    - Update README, SHOPPING_LIST and CLAUDE.md paths
    [numpad-B_Courtyard.gbr, numpad-B_Cu.gbl, numpad-B_Fab.gbr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]
2026-10-02 Switch to 2.5mm-lever power switch, EVQ-PUA02K reset
    The Alps SSSS811101 lever ended ~0.5mm inside the rear wall. An
    MSK-12C02-style slide switch with the H=2.5 lever fits the same pads and
    pokes ~0.53mm out of the case, so the nail scoop is gone. Reset button in
    the BOM is now the easier-to-find EVQ-PUA02K (same footprint).
    [case_bottom.stl, case_plate.stl]
2026-10-06 Move nice!nano 1.5mm to the edge, add its CAD model, USB scoop
    - nice!nano v2 STEP (kicad/3d/) is now the authority for the case's nano
    and USB-C geometry, and the MCU footprint's 3D model (rotate -90,
    offset 0.11/2.45, verified by exporting the board to STEP).
    - MCU moved 1.5mm toward the top edge (KiCad y 13.25 -> 11.75): nano edge
    flush with the PCB edge, USB-C 0.96 past it. Pin clearance improves to
    >=1.51. Re-routed (RAW re-routed alone after freerouting ran it over a
    PWR1 no-net pad); DRC 0 errors, 0 unconnected.
    - Case: USB window from the CAD model with 0.25 clearance, a 12.5x6.5 r1.5
    cable-head scoop whose back wall is flush with the USB mouth (collar
    inside the cavity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
    [case_bottom.stl, case_plate.stl, nice_nano_v2.step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]
2026-10-31 Rework stabilizer cutout, raise plate to 2.5mm, re-read KS-33 spec
    Stabilizer plate cutout now follows Gateron's suggested mounting
    (STEP-accurate: wings 6.0x12.5, 1.7x1.15 notch on the bar end, bars
    inward), replacing the earlier not-to-scale guess. Plate top raised
    2.2 -> 2.5mm (KS-33 flange height) so switches seat flat on the PCB.
    Updated KS-33, socket and JST figures from the re-read datasheets/
    drawings; regenerated case jscad/STL and assembly.json; refreshed
    README, SHOPPING_LIST and the handoff notes.
2026-11-08 Add KS-33G board, move tall-key diodes and JST, check part overlaps
    - KS-33G variant (numpad_ks33g): second ergogen PCB for Gateron LP 3.0
    switches with MX-pattern hotswap sockets (switch_mx_ks33g footprint,
    Ø5.0 NPTH centre). Same outline, plate, stabs and case as the KS-33
    board. Routed with keepout_dsn.py / strip_bad_nets.py; KiCad project,
    fab outputs and PCBWay package in kicad/.
    - Tall keys (Enter, +): D20/D21 moved to shift [-5.0, 1.25] (x 152.0);
    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
